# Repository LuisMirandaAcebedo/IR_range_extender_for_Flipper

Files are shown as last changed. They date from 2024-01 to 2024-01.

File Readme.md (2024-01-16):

# IR Range Extender for Flipper Zero

Flipper Zero has de ability of sending IR signals, but it has very short range.
This boards allows you to extend the range of your Flipper Zero using IR.

The difference with other boards is that this one has both wide angle (120º) group of high power IR emitters and narrow angle (14º) group of high power IR emitters, so you can reach undefined targets (when you don't know where exactly is the IR receiver) and far and well defined targets.

These groups of IR LEDs are selectable by a tiny switch.

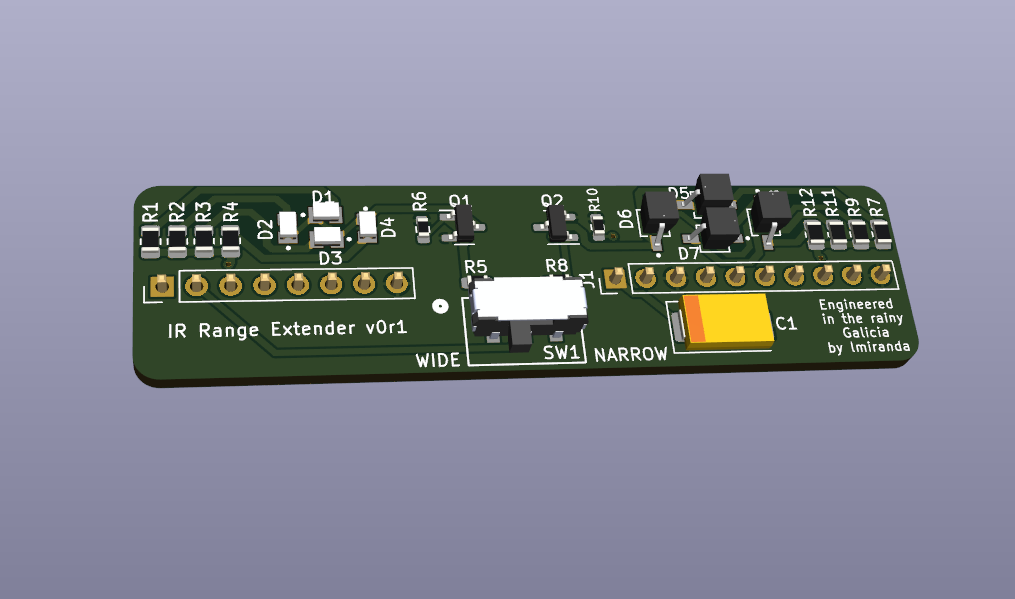
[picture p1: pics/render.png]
Render


The board connects to Flipper in a way that barely increases the size of the device.

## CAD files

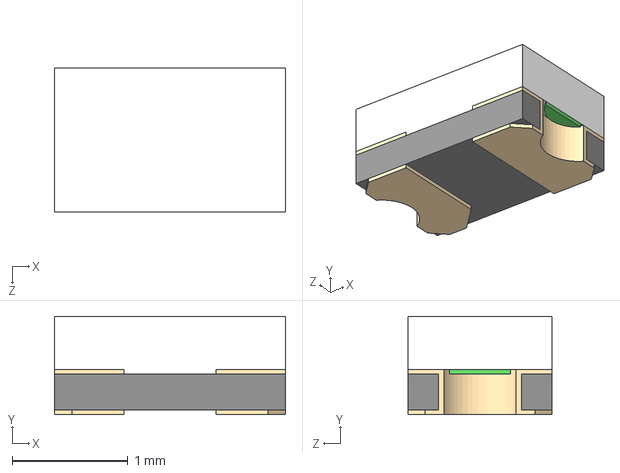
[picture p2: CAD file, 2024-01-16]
PCB/3D/VSMB1940ITX01.step
2.00 x 0.85 x 1.25 mm

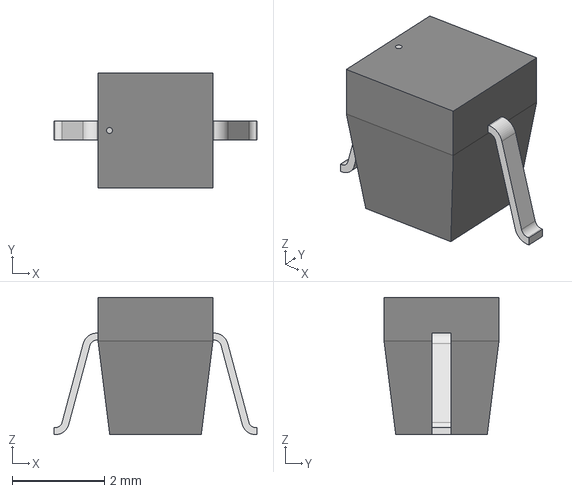
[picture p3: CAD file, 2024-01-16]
PCB/3D/CR_294008G_VIS.step
4.39 x 2.49 x 2.97 mm

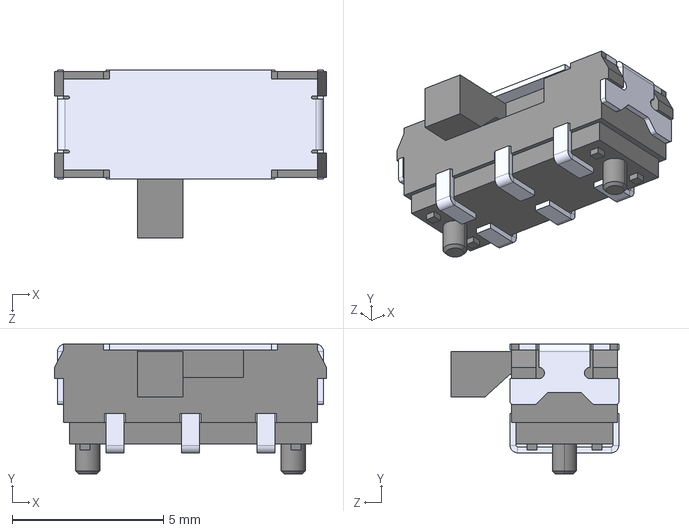
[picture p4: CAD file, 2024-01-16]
PCB/3D/JS202011JAQN.step
9.00 x 4.30 x 5.55 mm

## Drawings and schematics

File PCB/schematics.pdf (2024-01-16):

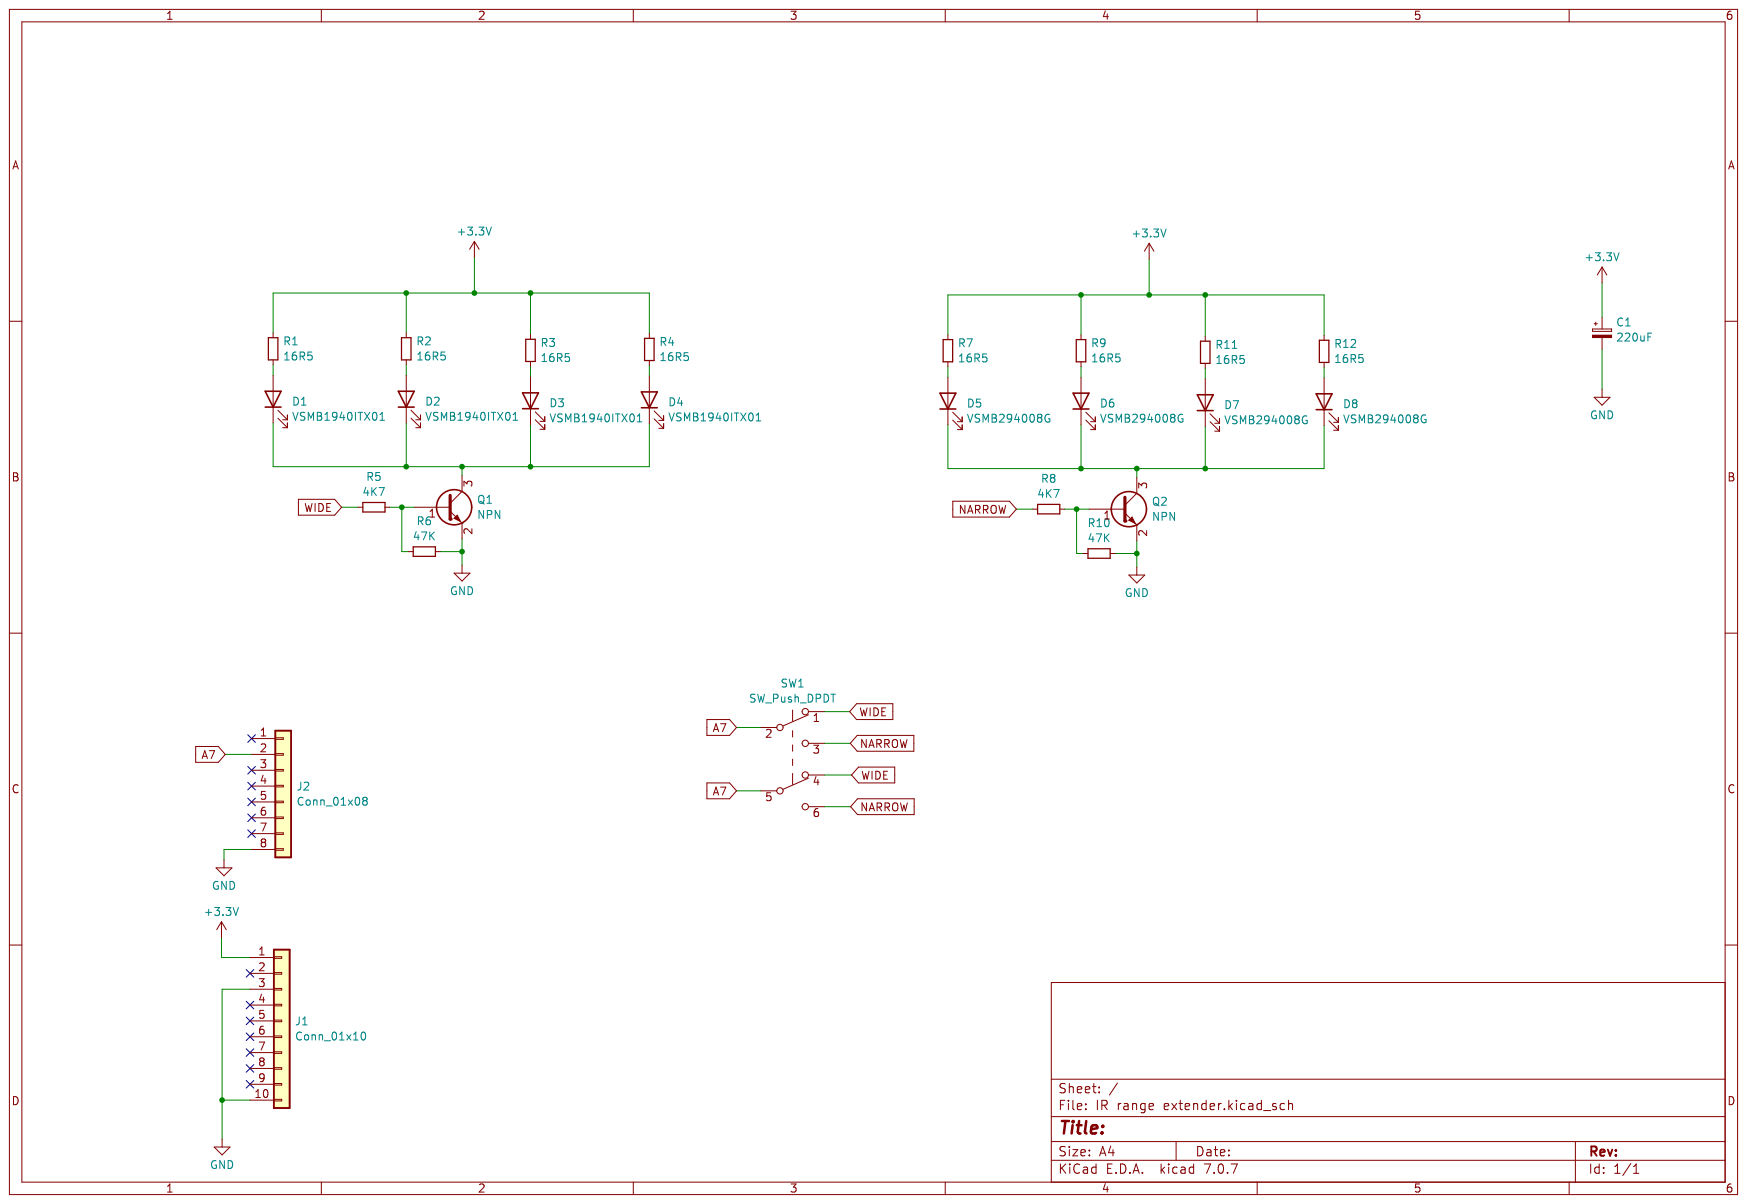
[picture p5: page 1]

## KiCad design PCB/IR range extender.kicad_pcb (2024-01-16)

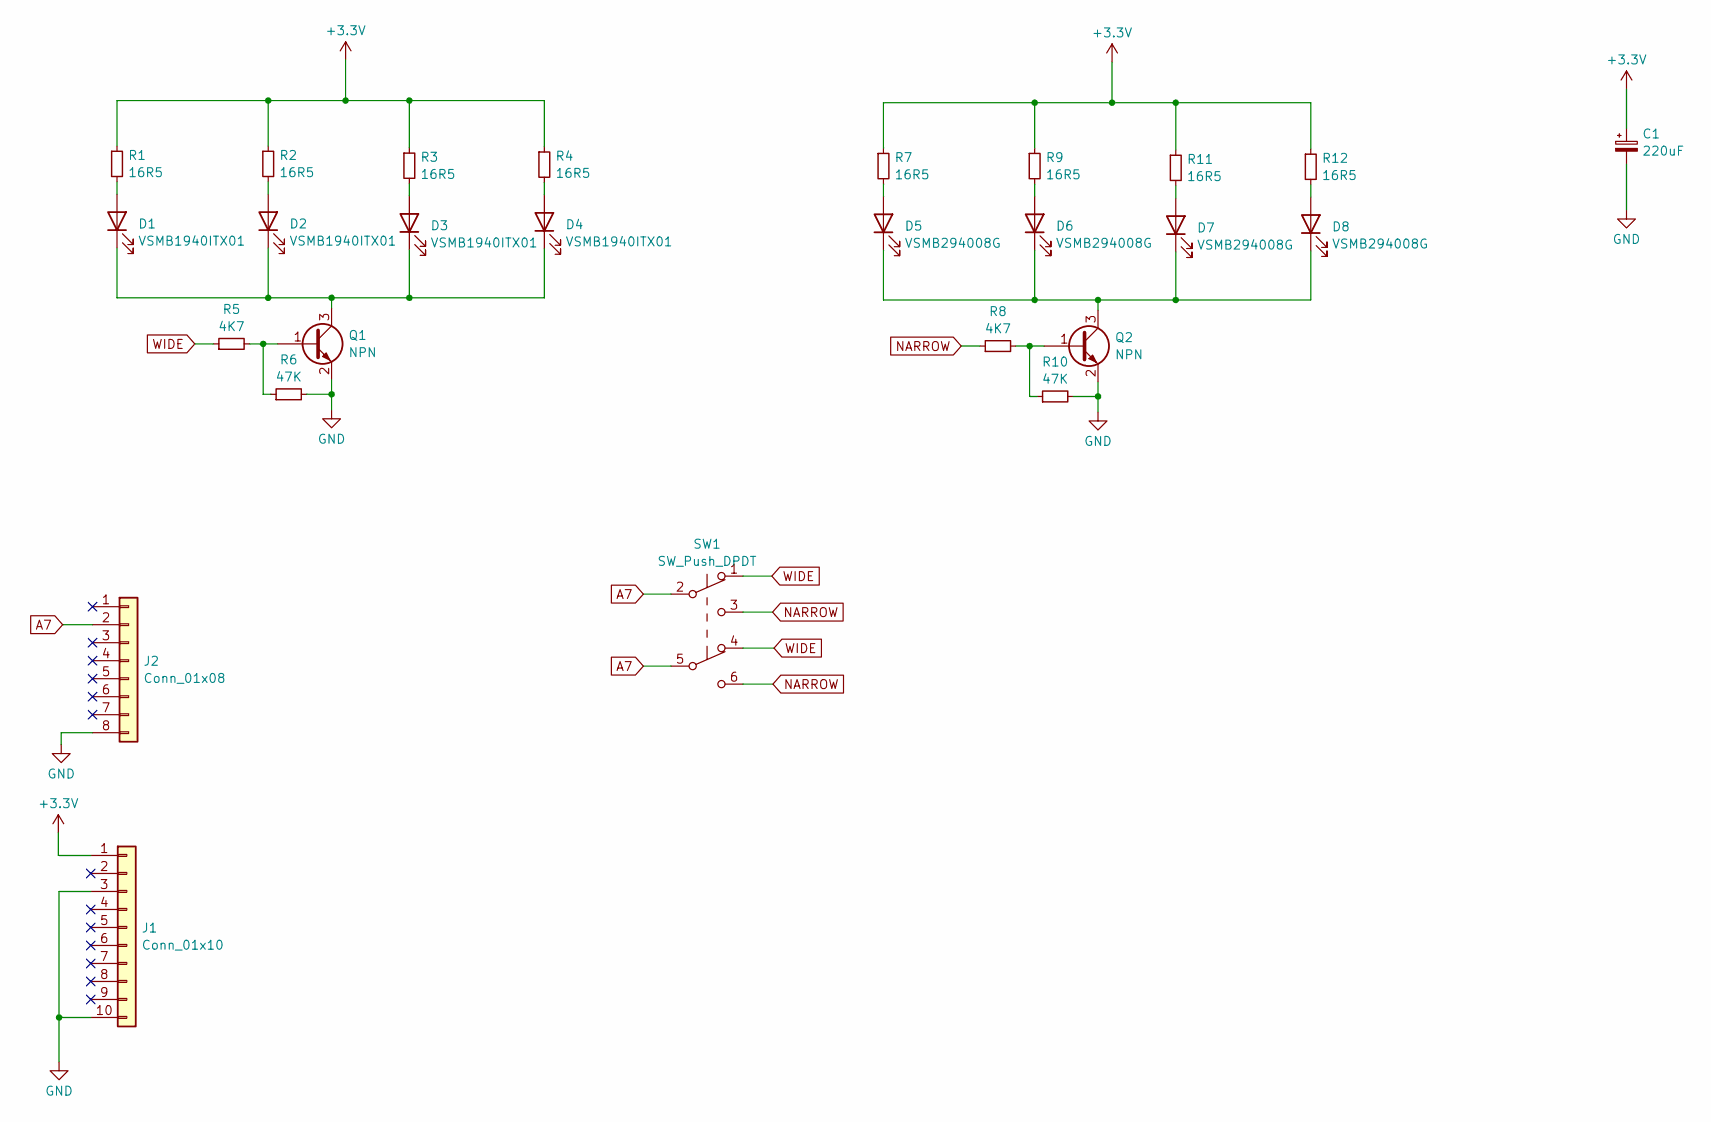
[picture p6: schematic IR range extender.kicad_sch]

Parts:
C1: 220uF; CP_EIA-7343-15_Kemet-W; Digi-Key_PN 718-293D227X06R3D2TE3CT-ND
D1, D2, D3, D4: VSMB1940ITX01; DIO_VSMB1940ITX01; Digi-Key_PN VSMB1940ITX01CT-ND
D5, D6, D7, D8: VSMB294008G; DIO_VSMB294008G; Digi-Key_PN VSMB294008GCT-ND
J1: Conn_01x10; PinHeader_1x10_P2.54mm_Vertical
J2: Conn_01x08; PinHeader_1x08_P2.54mm_Vertical
Q1, Q2: NPN; SOT-23-3; Digi-Key_PN NSS40201LT1GOSCT-ND
R1, R2, R3, R4, R7, R9, R11, R12: 16R5; R_0805_2012Metric; Digi-Key_PN 10-ERJ-P06F16R0VCT-ND
R5, R8: 4K7; R_0603_1608Metric; Digi-Key_PN 311-4.70KHRCT-ND
R6, R10: 47K; R_0603_1608Metric; Digi-Key_PN 311-47.0KHRCT-ND
SW1: SW_Push_DPDT; JS202011JAQN_CNK; Digi-Key_PN CKN10722CT-ND

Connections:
+3.3V: C1.1, J1.1, R1.1, R2.1, R3.1, R4.1, R7.1, R9.1, R11.1, R12.1
A7: J2.2, SW1.2 (B), SW1.5 (B)
GND: C1.2, J1.3, J1.10, J2.8, Q1.2 (E), Q2.2 (E), R6.2, R10.2
NARROW: R8.1, SW1.3 (C), SW1.6 (C)
unnamed: D1.2 (A), R1.2
unnamed: D1.1 (K), D2.1 (K), D3.1 (K), D4.1 (K), Q1.3 (C)
unnamed: D2.2 (A), R2.2
unnamed: D3.2 (A), R3.2
unnamed: D4.2 (A), R4.2
unnamed: D5.2 (A), R7.2
unnamed: D5.1 (K), D6.1 (K), D7.1 (K), D8.1 (K), Q2.3 (C)
unnamed: D6.2 (A), R9.2
unnamed: D7.2 (A), R11.2
unnamed: D8.2 (A), R12.2
unnamed: Q1.1 (B), R5.2, R6.1
unnamed: Q2.1 (B), R8.2, R10.1
WIDE: R5.1, SW1.1 (A), SW1.4 (A)

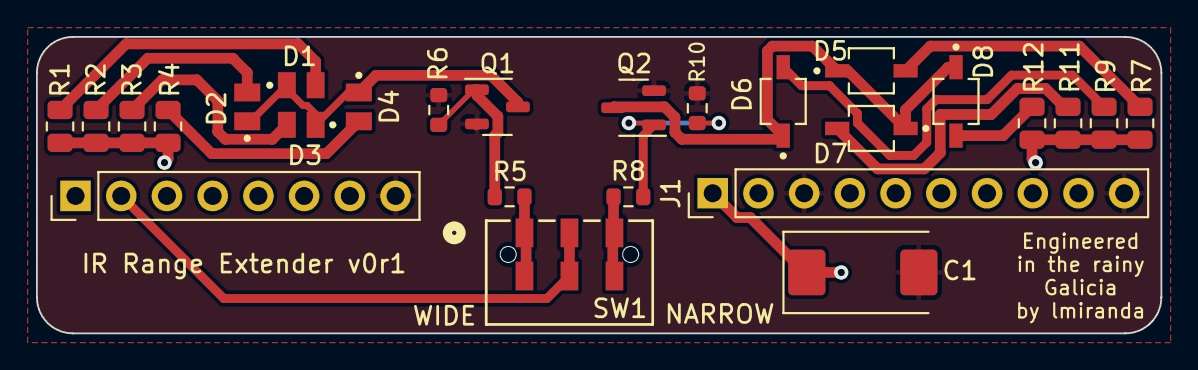
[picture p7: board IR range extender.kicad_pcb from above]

Board: 4 copper layers, 62.5 x 16.5 mm, 26 parts (0 on the bottom side), 17 nets.
